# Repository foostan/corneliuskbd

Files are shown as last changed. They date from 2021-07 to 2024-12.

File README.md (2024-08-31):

# Cornelius Keyboard

There are several version.
- v1: Cornelius, [geekhack](https://geekhack.org/index.php?topic=109741.msg2982321#msg2982321)
- v2: Cornelius Low-profile, [youtube](https://youtu.be/LSguWsNrmjk?si=NGWuKMaY3wJwlkxV)

This is the public repository for Cornelius keyboard series.
<p xmlns:cc="http://creativecommons.org/ns#" xmlns:dct="http://purl.org/dc/terms/"><span property="dct:title">Cornelius Keyboard</span> by <span property="cc:attributionName">foostan</span> is licensed under <a href="http://creativecommons.org/licenses/by-nc-sa/4.0/?ref=chooser-v1" target="_blank" rel="license noopener noreferrer" style="display:inline-block;">CC BY-NC-SA 4.0</a></p>

## v1 Cornelius
cornelius-photo
cornelius-details

## v2 Cornelius Low-profile
Pastry Keyboard Cornelius Low-profile (https://youtu.be/LSguWsNrmjk?si=_kJ-U84TBwFJ3C_R)

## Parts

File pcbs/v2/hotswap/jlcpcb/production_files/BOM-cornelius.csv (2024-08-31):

Comment | Designator | Footprint | LCSC
W25Q128JVSIQ | U3 | SOIC-8_5.23x5.23mm_P1.27mm | C113767
1k | R3,R5 | R_0402_1005Metric | C11702
NCP1117-3.3_SOT223 | U2 | SOT-223-3_TabPin2 | C146799
100n | C1,C2,C3,C4,C5,C6,C7,C8,C9 | C_0402_1005Metric | C1525
10u | C15,C16 | C_0402_1005Metric | C15525
27p | C12,C13 | C_0402_1005Metric | C1557
RP2040 | U1 | QFN-56-1EP_7x7mm_P0.4mm_EP3.2x3.2mm | C2040
SOD-523 | D1,D10,D11,D12,D13,D14,D15,D16,D17,D18,D19,D2,D20,D21,D22,D23,D24,D25,D26,D27,D28,D29,D3,D30,D31,D32,D33,D34,D35,D36,D37,D38,D39,D4,D40,D41,D42,D43,D44,D45,D46,D47,D48,D5,D6,D7,D8,D9 | D_SOD-523 | C232841
10k | R4 | R_0402_1005Metric | C25744
27 | R1,R2 | R_0402_1005Metric | C2909343
TS-1088R-02026 | BOOT_SW1,RESET_SW1 | TS-1088R-02026 | C455280
1u | C10,C11,C14 | C_0402_1005Metric | C52923
SW_Push | MX1,MX10,MX11,MX12,MX13,MX14,MX15,MX16,MX17,MX18,MX19,MX2,MX20,MX21,MX22,MX23,MX24,MX25,MX26,MX27,MX28,MX29,MX3,MX30,MX31,MX32,MX33,MX34,MX35,MX36,MX37,MX38,MX39,MX4,MX40,MX41,MX42,MX43,MX44,MX45,MX46,MX47,MX48,MX5,MX6,MX7,MX8,MX9 | keyswitch_choc12_hotswap_1u | C5333465
78171-0004 | J2 | Pico-EZmate_PCB_Header | C588524
12MHz 18pF | Y1 | Crystal_SMD_3225-4Pin_3.2x2.5mm | C91749

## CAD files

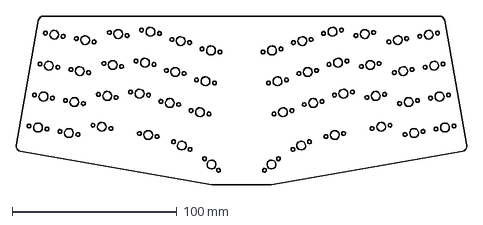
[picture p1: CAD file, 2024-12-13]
foams/v2/switch-ixpe-foam.dxf
273.2 x 102.5 mm

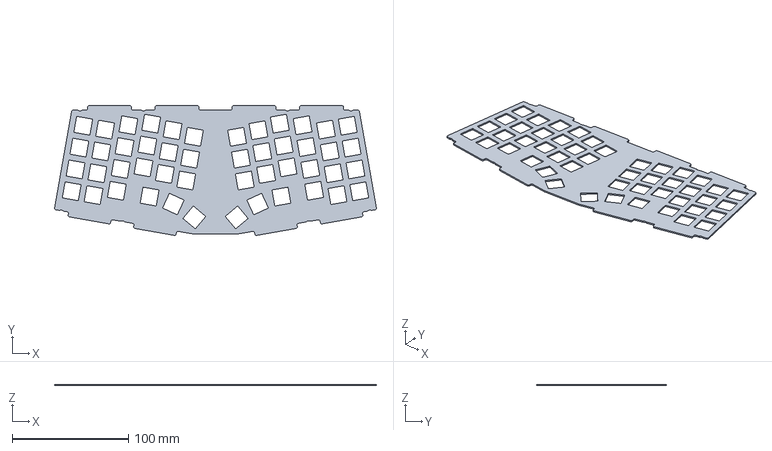
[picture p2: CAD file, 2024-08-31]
plates/v2/switch-plate.step
276.5 x 111.5 x 1.20 mm

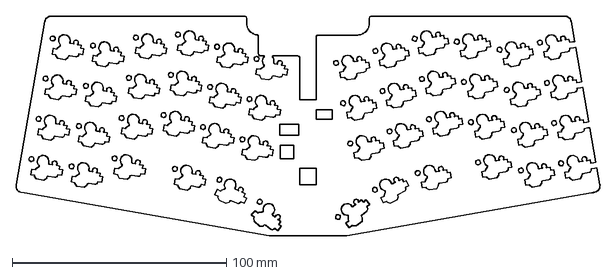
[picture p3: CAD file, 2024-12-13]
foams/v2/middle-foam.dxf
272.3 x 102.5 mm

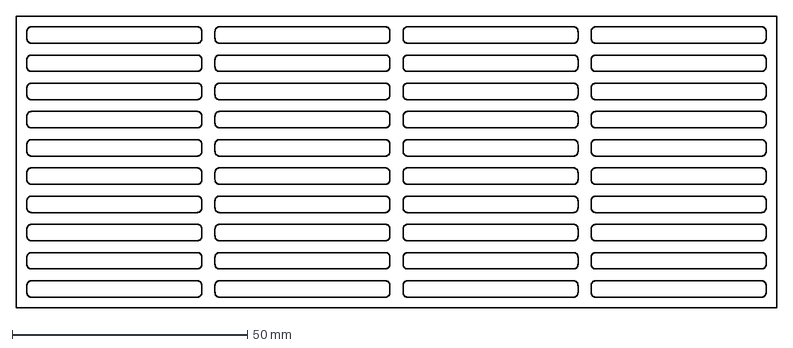
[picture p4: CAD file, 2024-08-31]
foams/v2/gasket-foam.dxf
161.7 x 62.0 mm

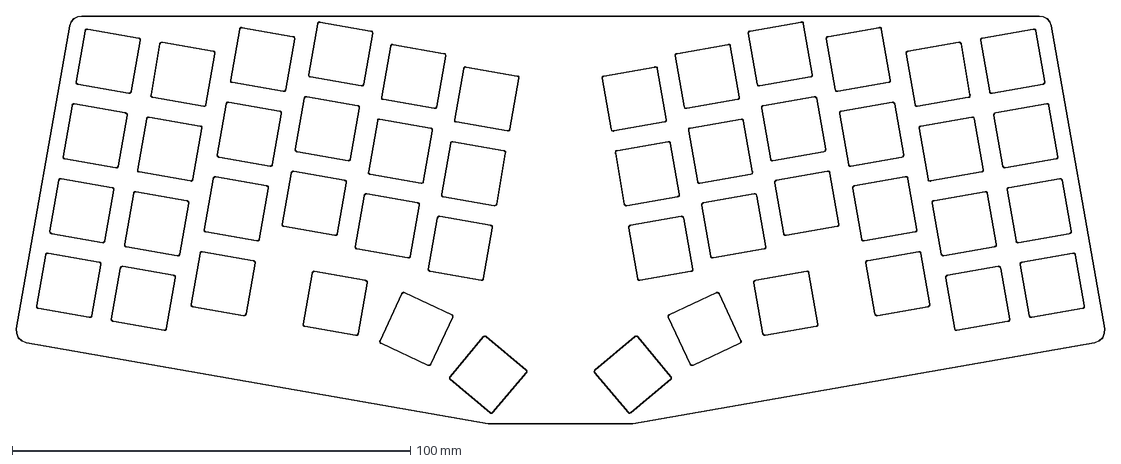
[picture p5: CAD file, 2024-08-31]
foams/v2/switch-foam.dxf
273.2 x 102.5 mm

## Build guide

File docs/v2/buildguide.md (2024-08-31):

# Build Guide / ビルドガイド

Pastry Keyboard Cornelius Low-profile (https://youtu.be/LSguWsNrmjk?si=_kJ-U84TBwFJ3C_R)

## In the box / 箱の中身












## Insert switches / スイッチの取り付け


Please confirm the direction of switches.\
スイッチの向きに注意してください。


Insert the switch foam from the backside of the switches. There are no two sides.\
スイッチの裏側にスイッチフォームをセットします。裏表はありません。



Please insert switches firmly into each socket.\
スイッチをソケットにしっかりと差し込んでください。

## Flash the firmware / ファームウェアの書き込み





Please download uf2 file at here.\
こちらからuf2ファイルをダウンロードしてください。

[cornelius_rev2_via.uf2](https://github.com/foostan/kbd_firmware/raw/main/keyboards/cornelius/qmk/qmk_firmware/.build/cornelius_rev2_via.uf2)

Connect your PC and drop the downloaded uf2 file into the RPI-PR2 device to complete flash.\
PCに接続し、ダウンロードしたuf2ファイルをRPI-PR2デバイスにドロップすると書き込みが完了します。

### When writing firmware for the second time / 2回目以降にファームウェアを書き込む場合


Connect to the PC while holding down the BOOT button, or while connected to the PC, hold down the BOOT button and press the RESET button. After that, an RPI-PR2 device will be mounted.\
BOOTボタンを押しながらPCに接続するか、PCに接続した状態でBOOTボタンを押しながらリセットボタンを押します。 すると、RPI-PR2デバイスがマウントされます。

### Change your keymap / キーマップの書き換え

Please download json file for VIA at here.\
こちらからVIA用のjsonファイルをダウンロードしてください。

[cornelius_rev2.json](https://github.com/foostan/kbd_firmware/raw/main/keyboards/cornelius/the-via/cornelius_rev2.json)

Please reference this [page](https://github.com/foostan/crkbd/blob/main/docs/firmware/rev4/firmware_en.md#change-your-keymap) to change your keymap.\
こちらの[ページ](https://github.com/foostan/crkbd/blob/main/docs/firmware/rev4/firmware_jp.md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)を参考にしてキーマップを書き換えます。

## Attach gasket parts / ガスケットパーツの取り付け




There are 16 attaching points on both sides of the plate in total.\
取り付け場所はプレートの表裏に全部で16箇所あります。

## Mount daughter board / ドーターボードの取り付け



This is the most difficult part of the building.
Please make sure to attach the cable firmly so that it does not come off.\
ここが組み立ての最難関場所です。
ケーブルが外れないようにしっかりと付けてください。





Close the top of the case making sure the foam is correct in place.\
フォームがずれていないことを確認してケースを閉じます。

## Attach rubber feet / ゴム足の取り付け



There are 4 attaching points in total.\
取り付け場所は全部で4箇所あります。

## Attach keycaps / キーキャップの取り付け


## Completed / 完成


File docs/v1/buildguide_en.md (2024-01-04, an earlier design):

# Build Guide
## Checking the package contents
When you open the box, first make sure all the contents are included.

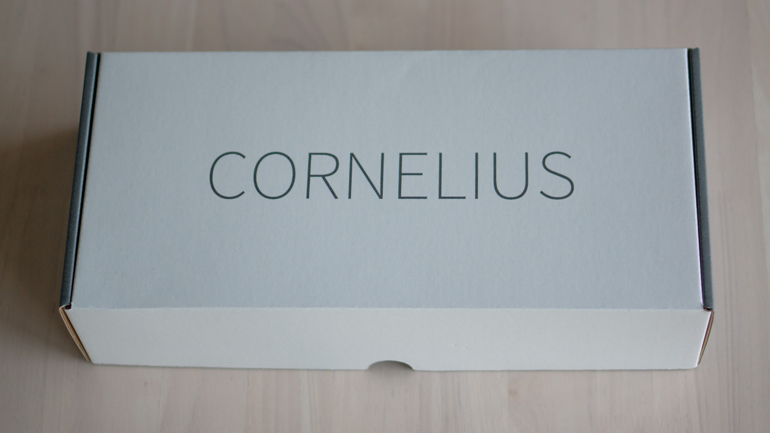
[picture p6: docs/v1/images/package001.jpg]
Package 001


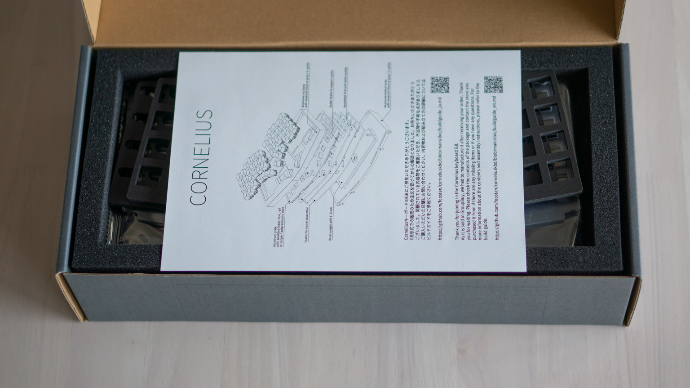
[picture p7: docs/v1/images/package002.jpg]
Package 002


__Keyboard case body__.

The top and bottom bodies are screwed together with spare screws beforehand.
Please remove the screws and check the inside.

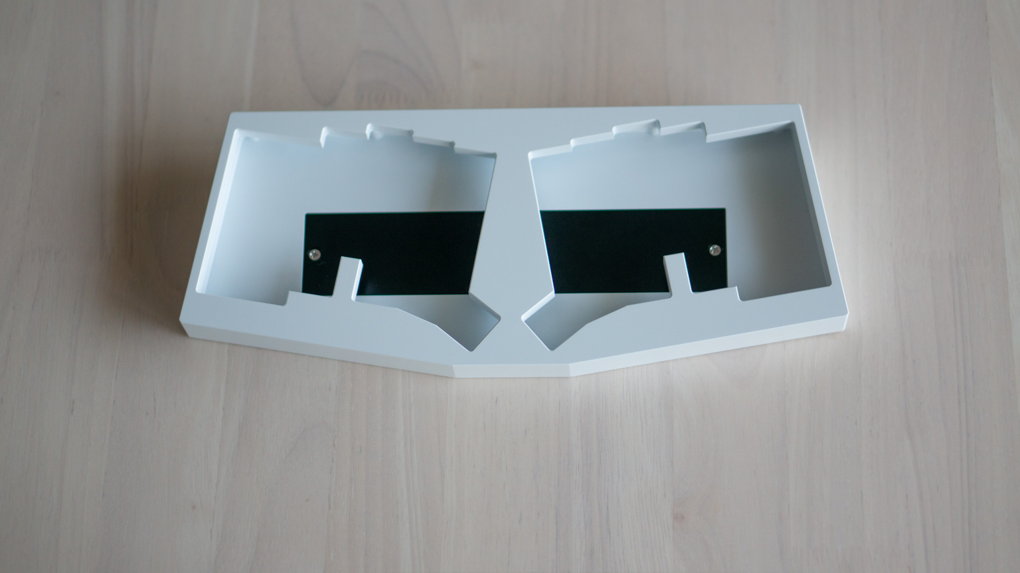
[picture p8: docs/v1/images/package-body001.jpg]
Package Body 001


The inside of the case and other parts that are not visible from the front when assembled may have some scratches or may not be painted sufficiently.
In most cases, this is difficult to prevent due to the manufacturing process, so we appreciate your understanding.

Also, there may be a separate clearance problem with the E-White case, so please refer to [the following](#the-clearance-between-the-e-white-case-and-each-part).

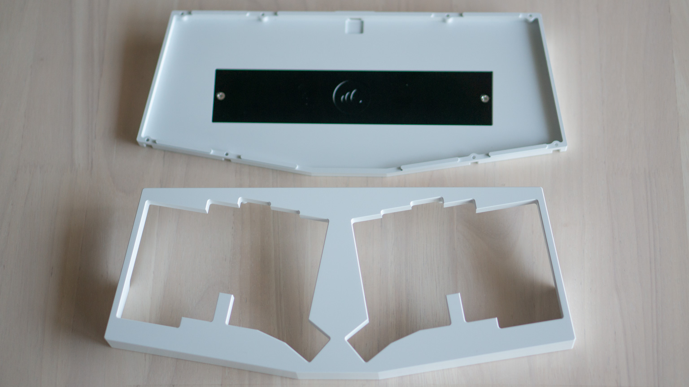
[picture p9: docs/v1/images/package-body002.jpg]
Package Body 002


__PCB__

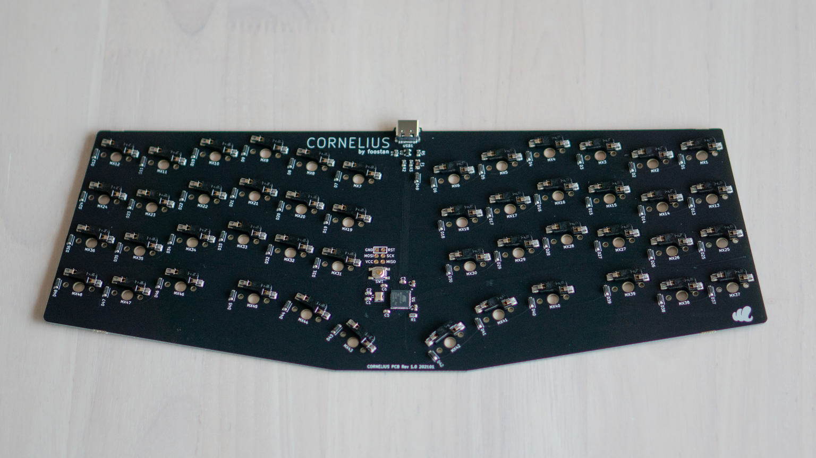
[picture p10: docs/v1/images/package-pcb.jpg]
Package PCB


__Switch plate__

Please make sure the one you have chosen is included.

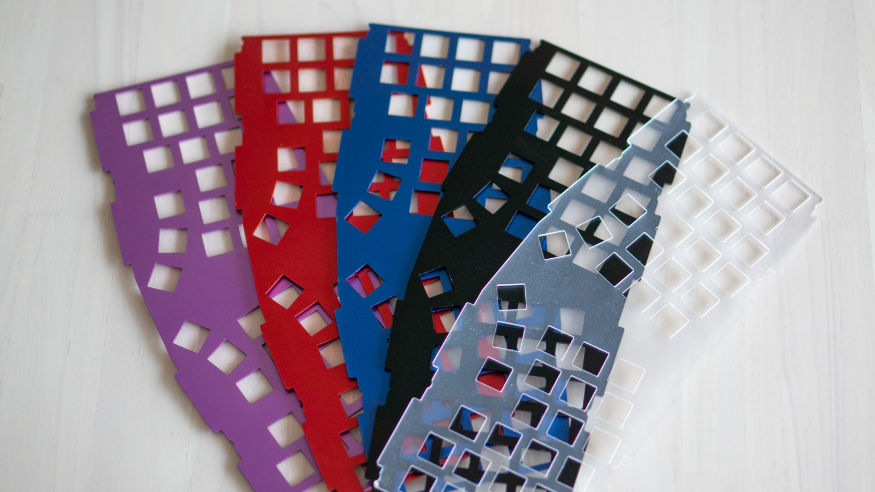
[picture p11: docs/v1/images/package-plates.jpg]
Package Plates


__Foam__

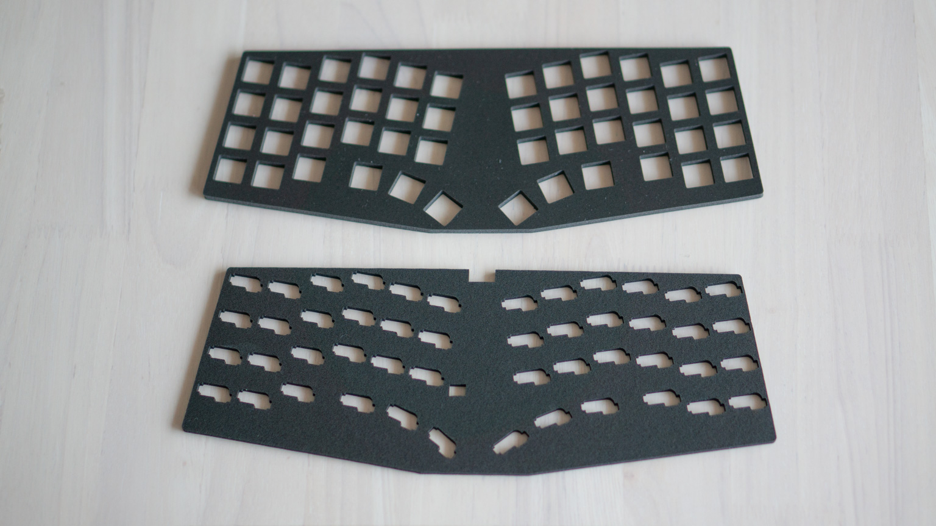
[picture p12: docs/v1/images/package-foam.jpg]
Package Foam


__Gasket foam__

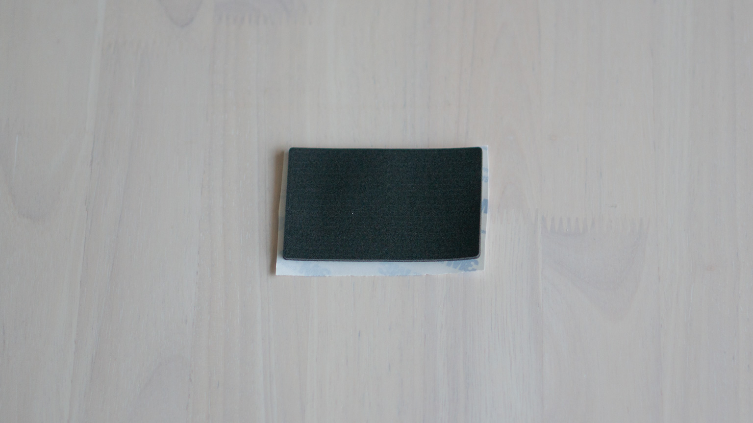
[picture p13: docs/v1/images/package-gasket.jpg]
Package Gasket


__Screws etc.__

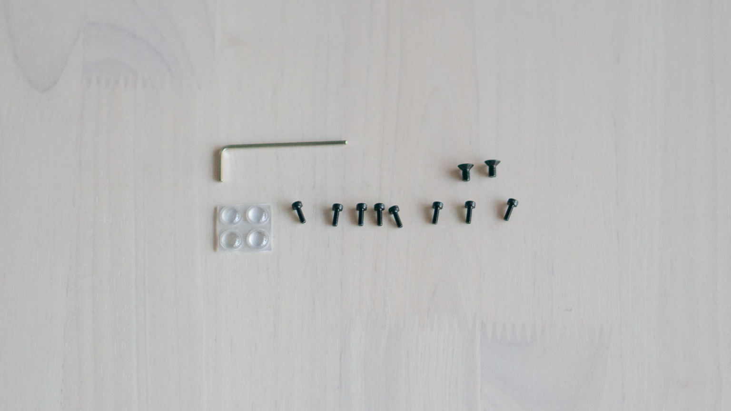
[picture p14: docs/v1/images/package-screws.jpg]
Package Screws


## The clearance between the E-White case and each part

For E-White, some changes were made to the coating process at the GB manufacturing stage to improve quality.
As a result, the surface texture and the white color have been greatly improved.

However, this has resulted in a thicker coating surface than before, which has caused a lack of clearance for some parts.
Specifically, interference may occur between the top body and bottom body, and between the top body and switch plate, depending on the combination of the machining accuracy of each part.

If you are concerned about interference, or if an assembly is difficult, please refer to [the following solutions](#how-to-fix-the-clearance-between-the-e-white-case-and-each-part).
Please check and deal with them before assembly.
Additionally, some of them have been handled for us before shipment.

## Check PCB operation

Before you start assembling, please make sure that the PCB is working properly.

We recommend you to use [VIA](https://caniusevia.com/) or [Remap](https://remap-keys.app/) to check the operation, since VIA-compatible firmware has already been written.

BTW, when you need to use the newest firmware then you should confirm [here](https://github.com/foostan/crkbd/blob/main/doc/firmware_en.md) as a reference to flash.
Download the firmware of VIA from the following link.

[foostan_cornelius_via.hex](https://raw.githubusercontent.com/foostan/qmk_firmware-hex/main/.build/foostan_cornelius_via.hex)

__Verification with VIA's Test Matrix__

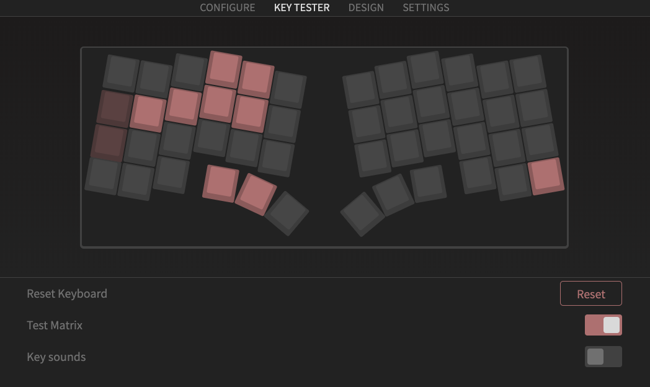
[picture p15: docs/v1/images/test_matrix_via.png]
Test Matrix by VIA


__Verify by Test Matrix by Remap__

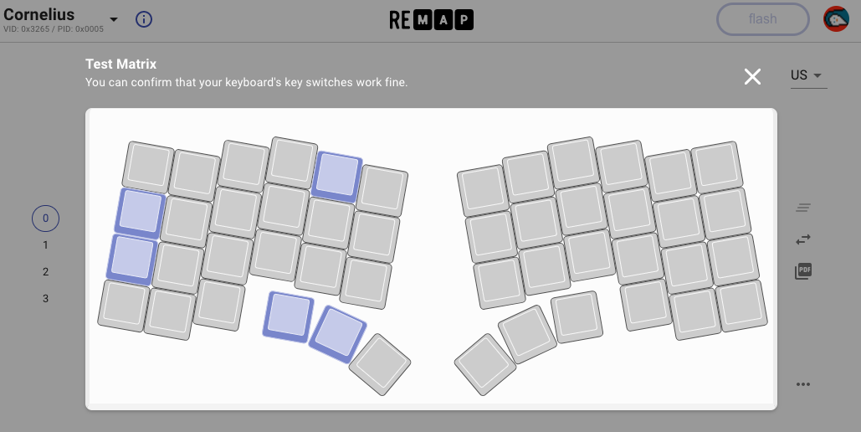
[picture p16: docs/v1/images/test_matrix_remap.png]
Test Matrix by Remap


## Install the gasket foam.

Install the gasket foam on the bottom body and the top body.
You can also install it on the switch plate instead of the case.

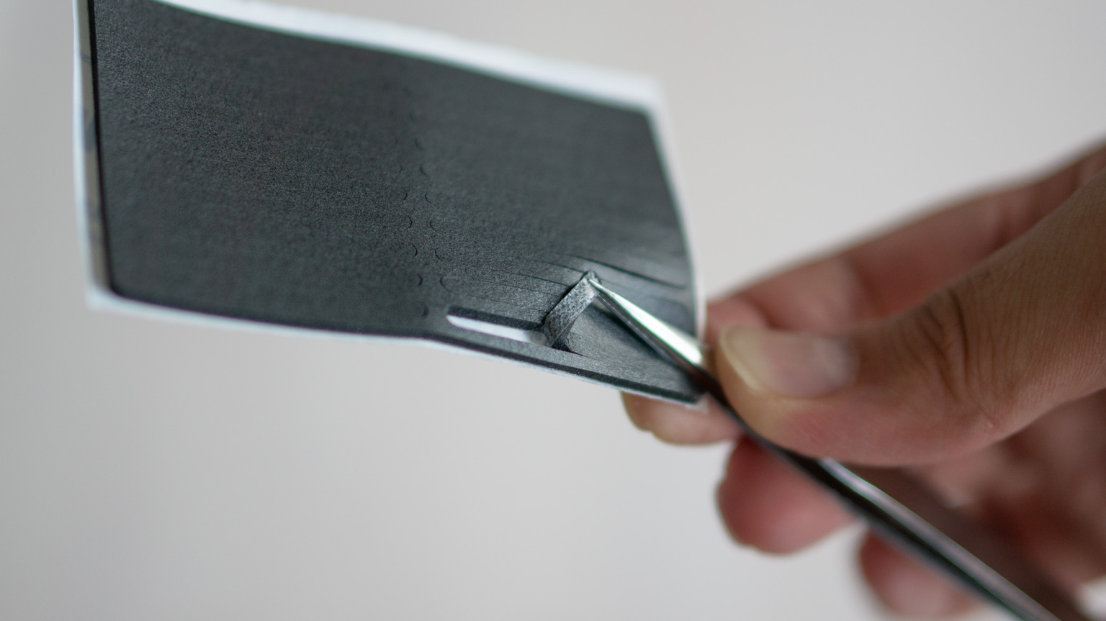
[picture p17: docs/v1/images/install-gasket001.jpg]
Install Gasket


When removing the gasket foam, be careful not to tear the foam.
Also, there is adhesive tape on one side of the gasket foam. Depending on how you remove it, the adhesive side may remain on the filme side, so it is recommended to carefully remove it with tweezers.

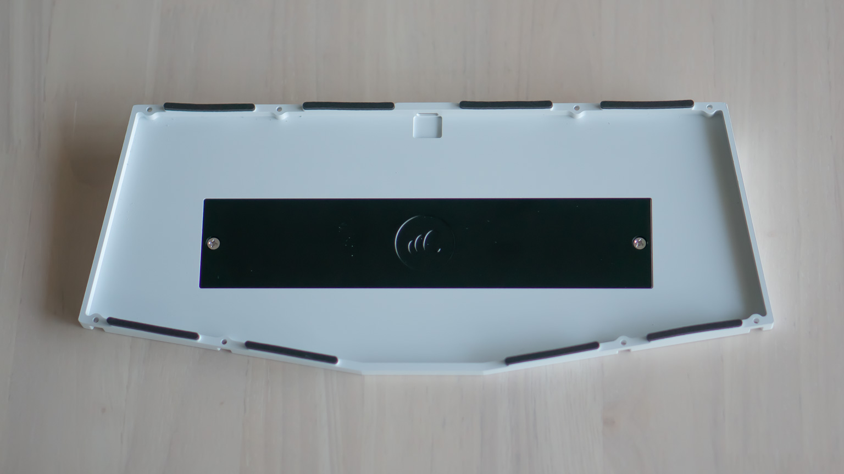
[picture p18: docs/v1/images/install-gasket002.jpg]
Install Gasket


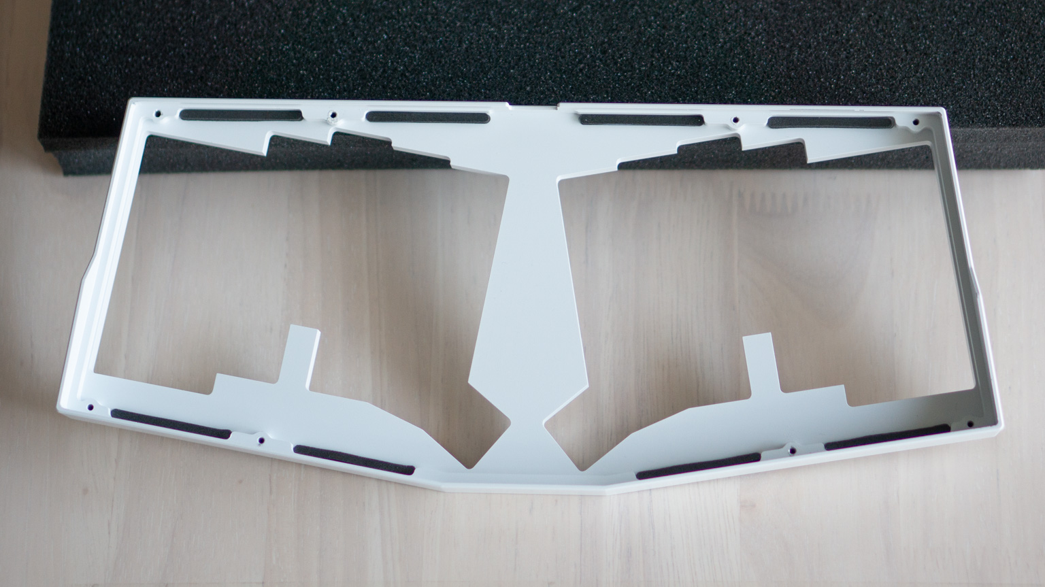
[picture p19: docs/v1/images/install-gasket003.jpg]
Install Gasket


## Installing the switch

For the polycarbonate plate, there is a protective film on both sides, so carefully peel it off.

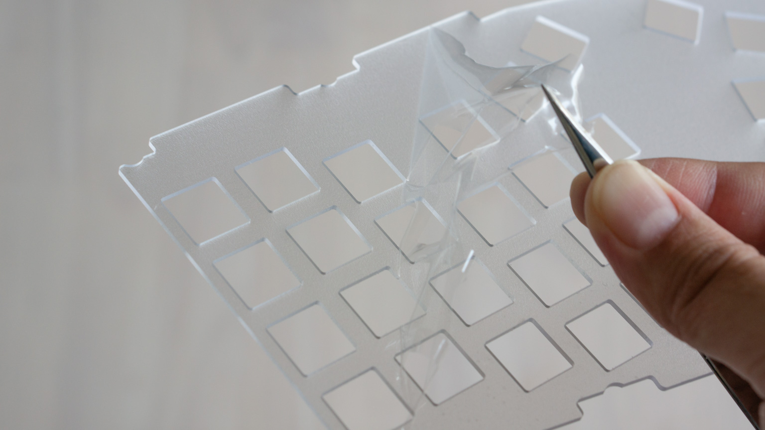
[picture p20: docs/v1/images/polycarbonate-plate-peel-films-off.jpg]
Polycarbonate plate Peel films off


The polycarbonate plate has a glossy side and a semi-glossy side. The two sides of the plate are the same, so you can use whichever side you prefer.

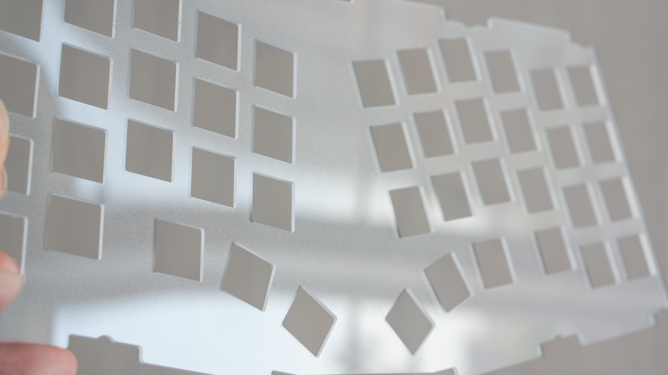
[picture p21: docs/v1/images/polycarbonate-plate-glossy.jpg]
Polycarbonate plate Glossy


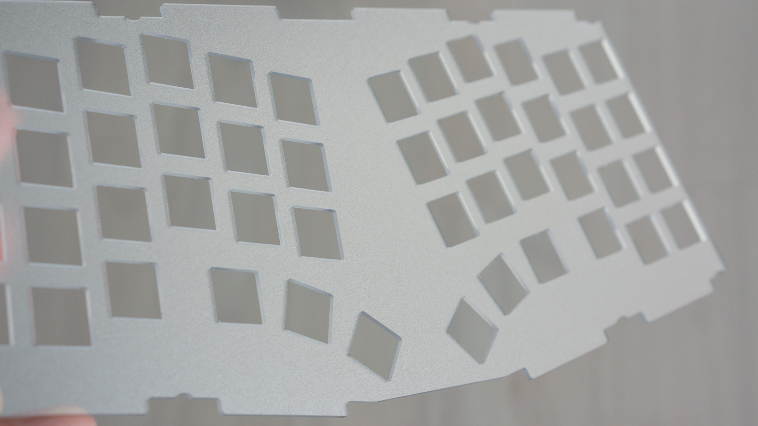
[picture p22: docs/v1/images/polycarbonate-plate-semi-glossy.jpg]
Polycarbonate plate Semi-Glossy


Insert the switch foam between the PCB and the switch plate, and then attach the switch.

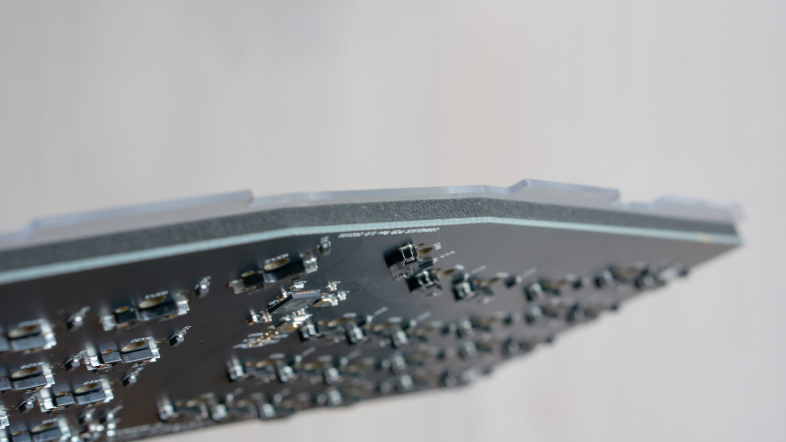
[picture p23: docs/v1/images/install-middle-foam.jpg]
Install Middle foam


When attaching the switch, press it straight down from the top.
Place the PCB on a flat surface as shown in the photo, and push it in from directly above for easier insertion.

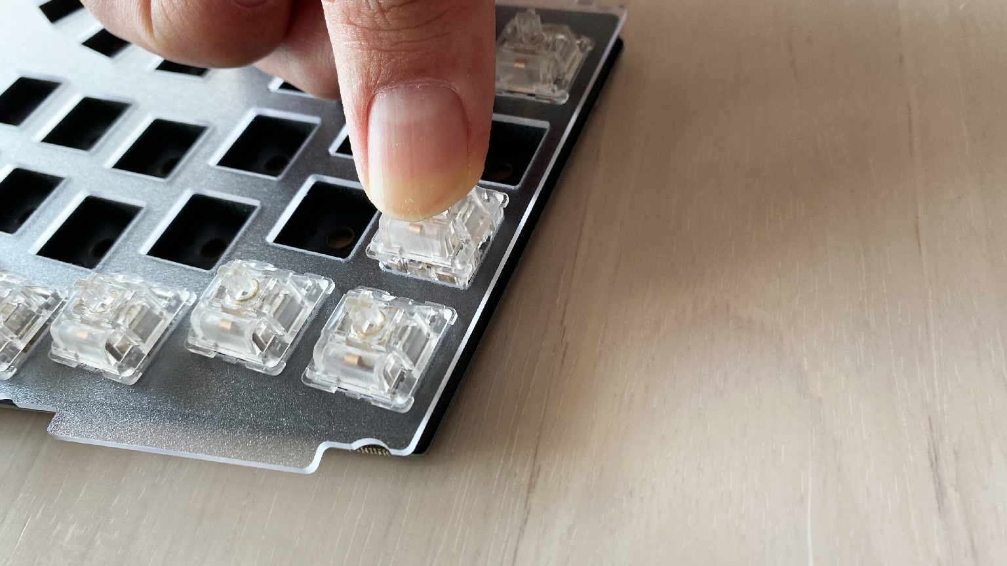
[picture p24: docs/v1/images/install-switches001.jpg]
Install Switches 001


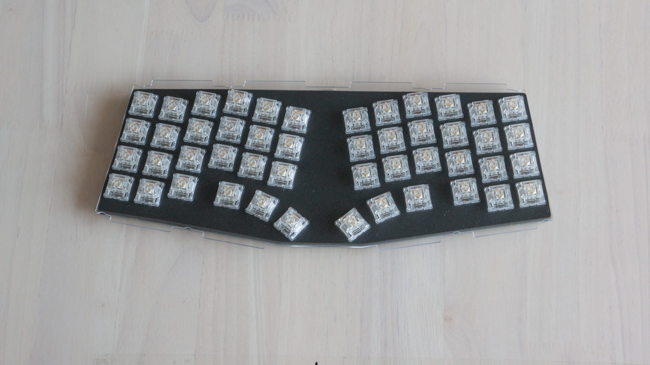
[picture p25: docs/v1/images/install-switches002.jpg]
Install Switches 002


If you are using a solderable board, you can also solder it here.

## Case assembly

The weights on the bottom body are initially attached with silver screws.
You can change them to black screws if you like.

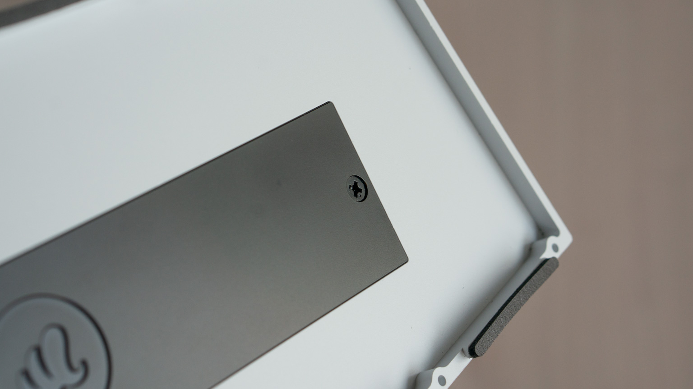
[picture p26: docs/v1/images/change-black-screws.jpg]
Change black screws


Put the bottom foam on the bottom of the bottom body, and put the PCB on top of it.

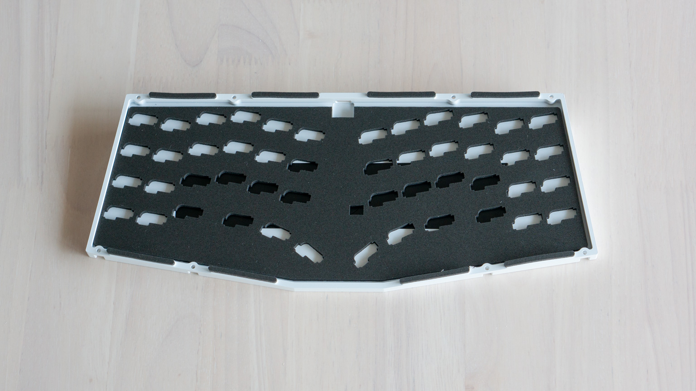
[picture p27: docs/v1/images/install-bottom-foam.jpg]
Install a bottom foam


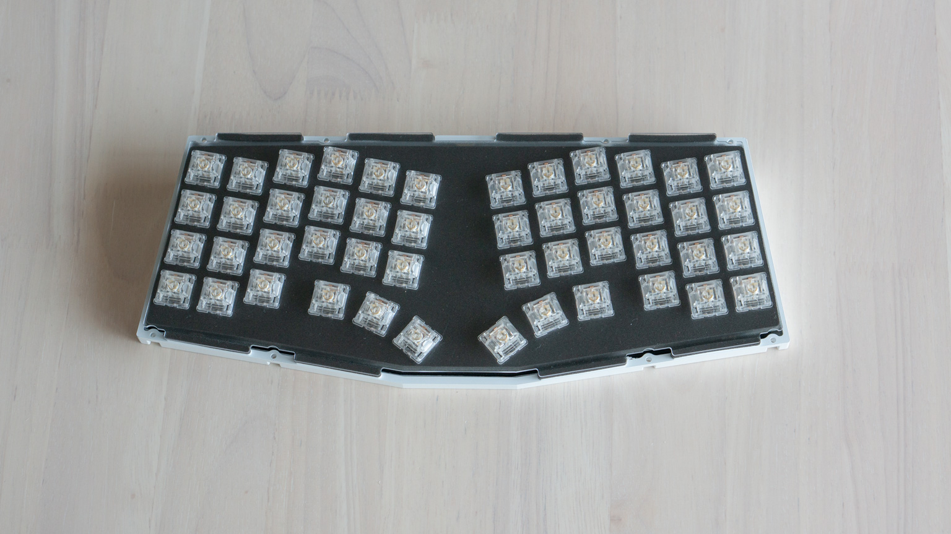
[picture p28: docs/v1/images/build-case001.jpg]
Build a case 001


Install the top body straight from the top and while holding the top body by hand to prevent it from coming off, attach the screws from the back.

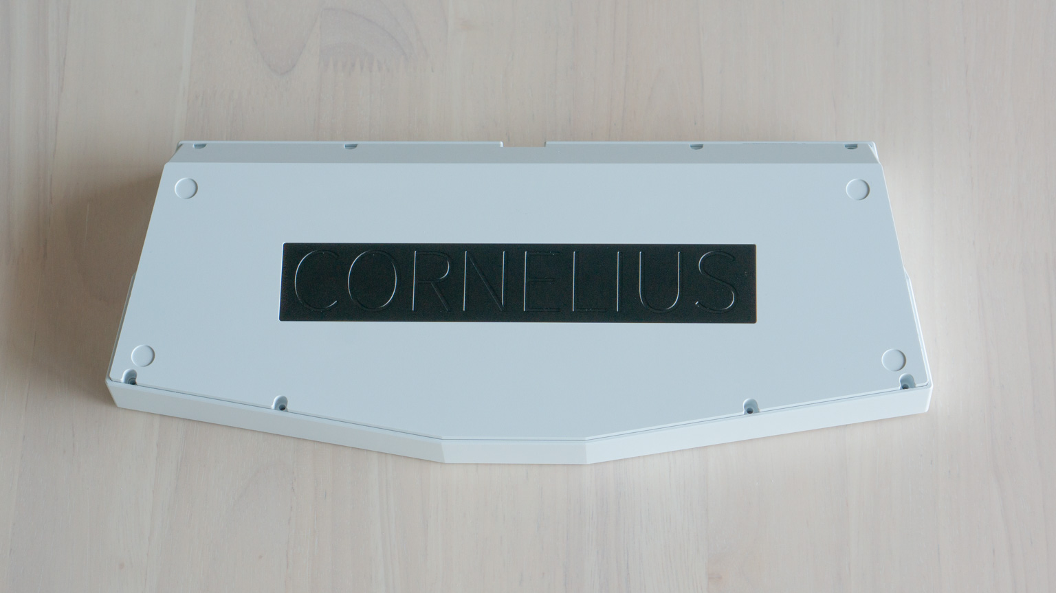
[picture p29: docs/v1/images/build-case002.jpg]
Build a case 002


Attach cushion rubbers.

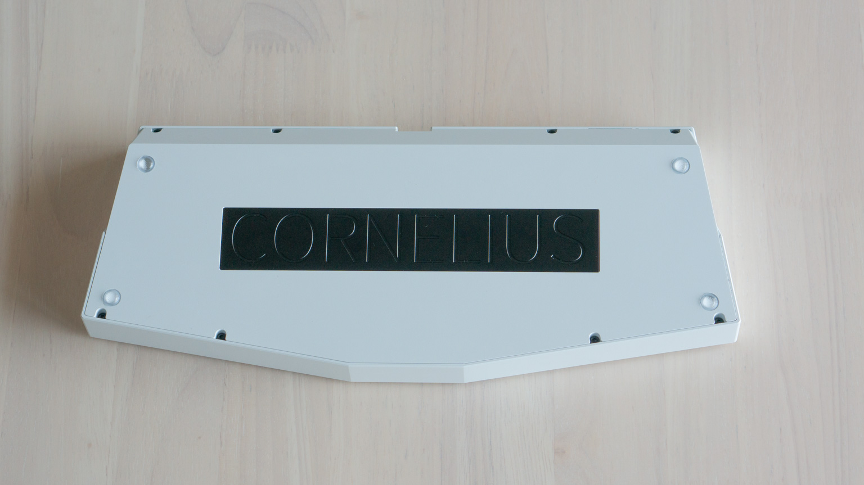
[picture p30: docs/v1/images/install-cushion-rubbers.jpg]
Install cushion rubbers


Finally, attach the key cap to complete the process.

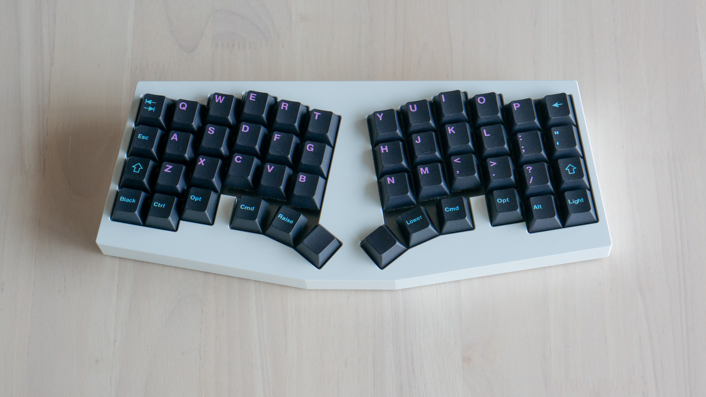
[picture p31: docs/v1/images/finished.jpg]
Finished


## how to fix the clearance between the E-White case and each part

The following is a step-by-step explanation of how to fix with interference between the top body and bottom body, and between the top body and plate.
Please note that it is necessary to remove about 0.1mm-0.2mm with a sandpaper. In the example shown here, we used a JIS standard #240. If you use a sandpaper with too rough a grit, it may damage the main body greatly, so it is safer to use a medium to fine grit sandpaper of #240-#400.

The number of the sandpaper varies depending on the standard. The JIS standard #240-#400 is roughly the same as the following for other standards.
- The United States CAMI: 240-320
- The European FEPA: P220-P400

The degree of shaving varies depending on the individual unit, so please check each time while working to avoid over-shaving.
I apologize for any inconvenience this may cause.

### When the top body and bottom body interfere with each other

If you feel a little resistance when opening and closing the top and bottom bodies, there is no problem.
However, if you feel it is too tight, first lightly scrape the following area on the bottom body.
It depends on the individual, but please refer to the following pictures.

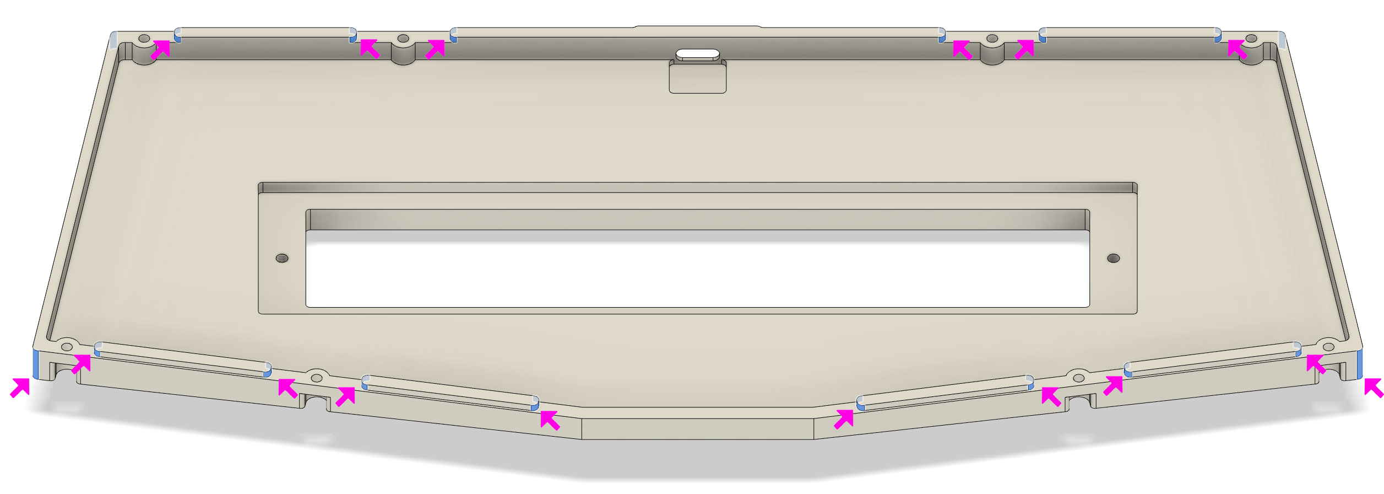
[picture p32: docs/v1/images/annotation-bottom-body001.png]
Annotation Bottom body 001


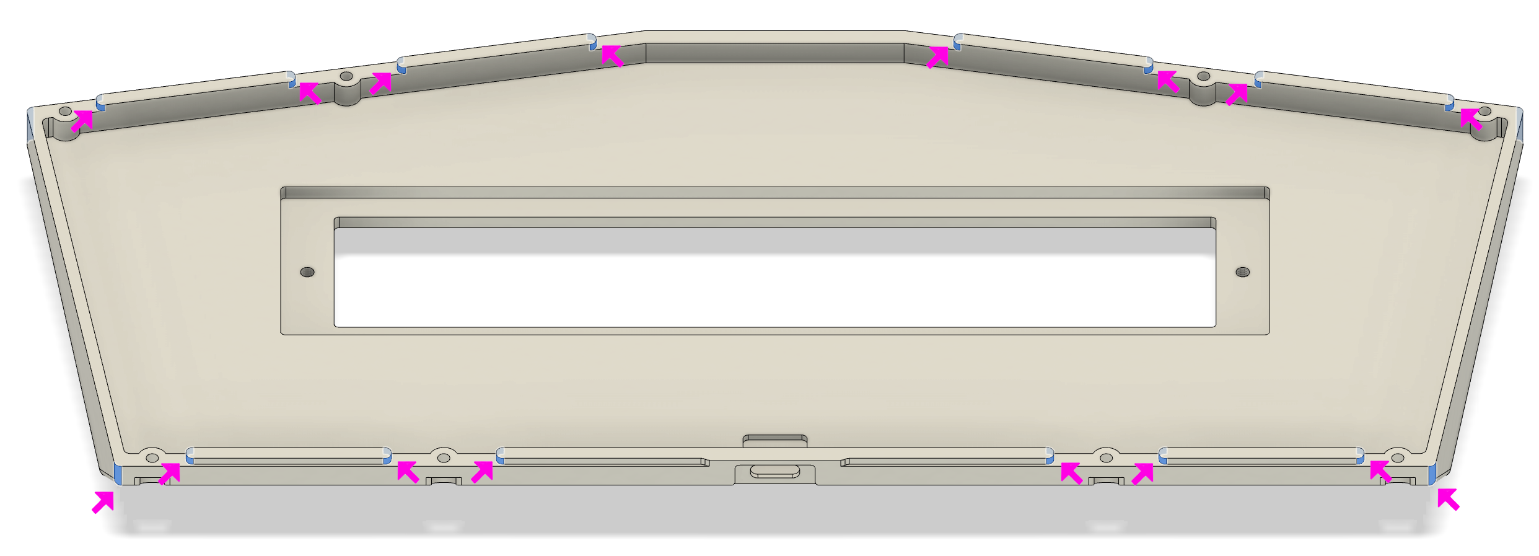
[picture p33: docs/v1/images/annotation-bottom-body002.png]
Annotation Bottom body 002


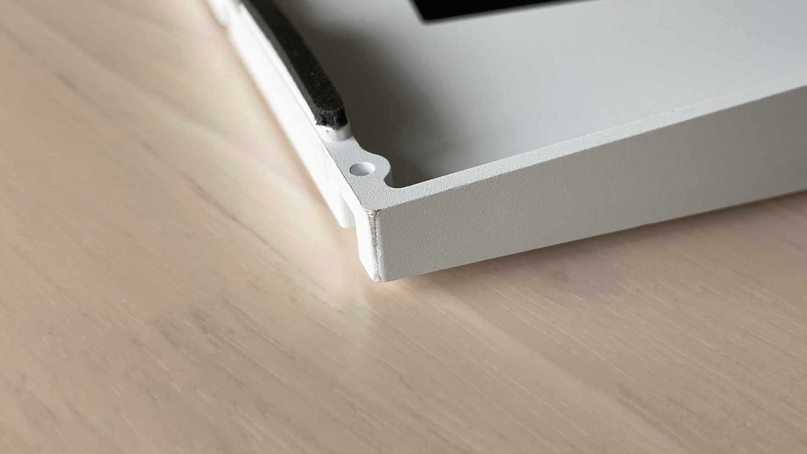
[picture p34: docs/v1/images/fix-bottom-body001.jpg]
Fix Bottom body 001


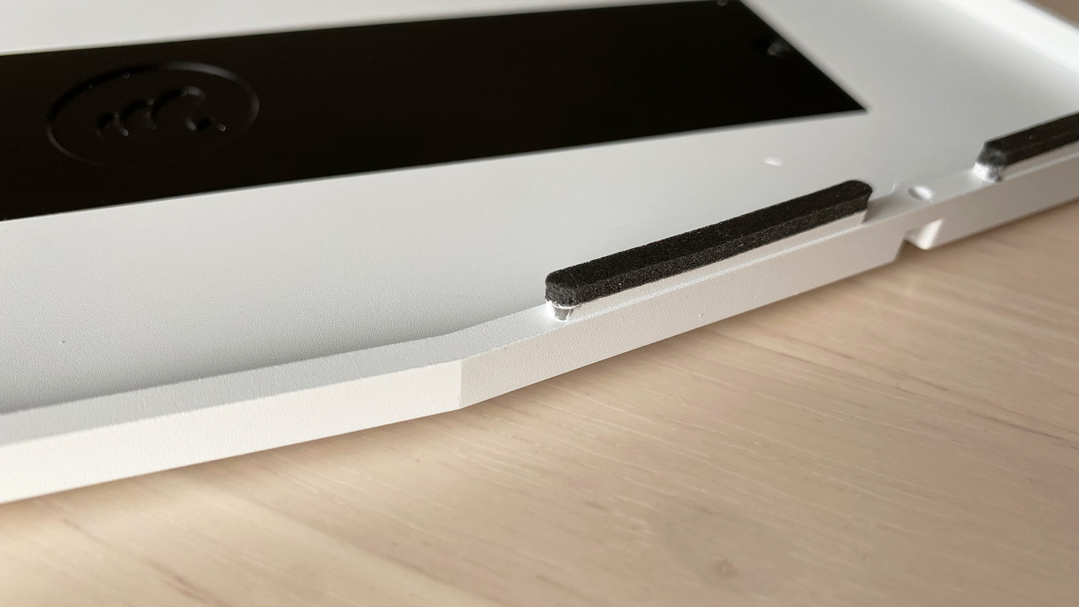
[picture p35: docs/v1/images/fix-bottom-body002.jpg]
Fix Bottom body 002


If the bottom body does not solve the problem, lightly scrape the following areas on the top body.
However, it is not recommended to shave this area as it is difficult to do so.

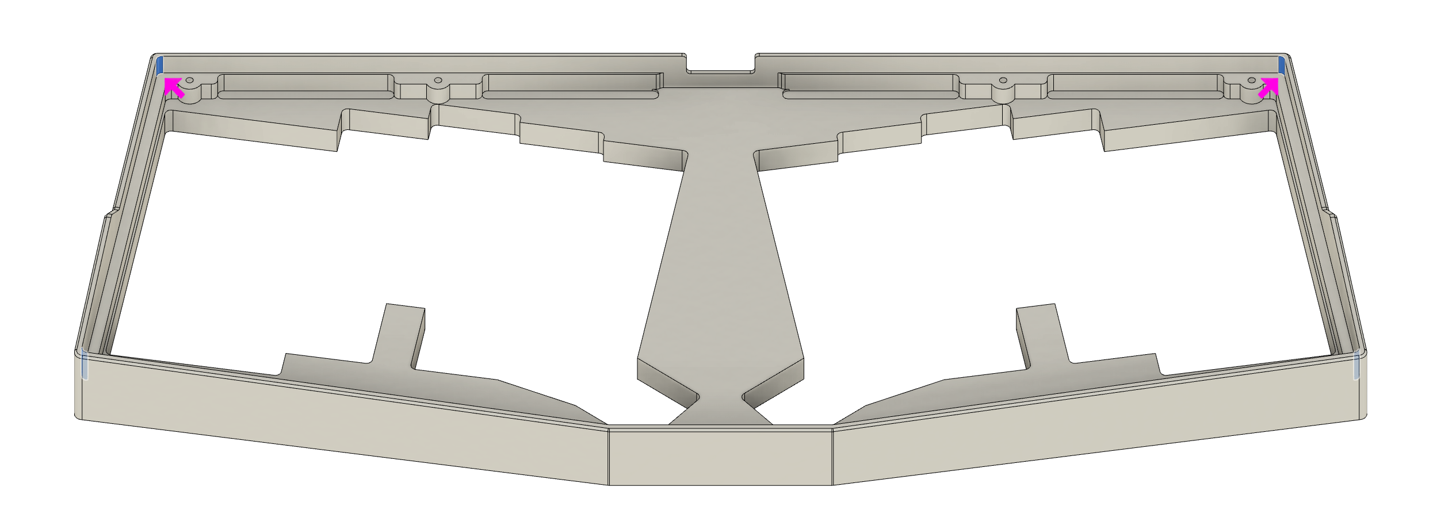
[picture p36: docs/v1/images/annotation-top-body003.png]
Annotation Top body 003


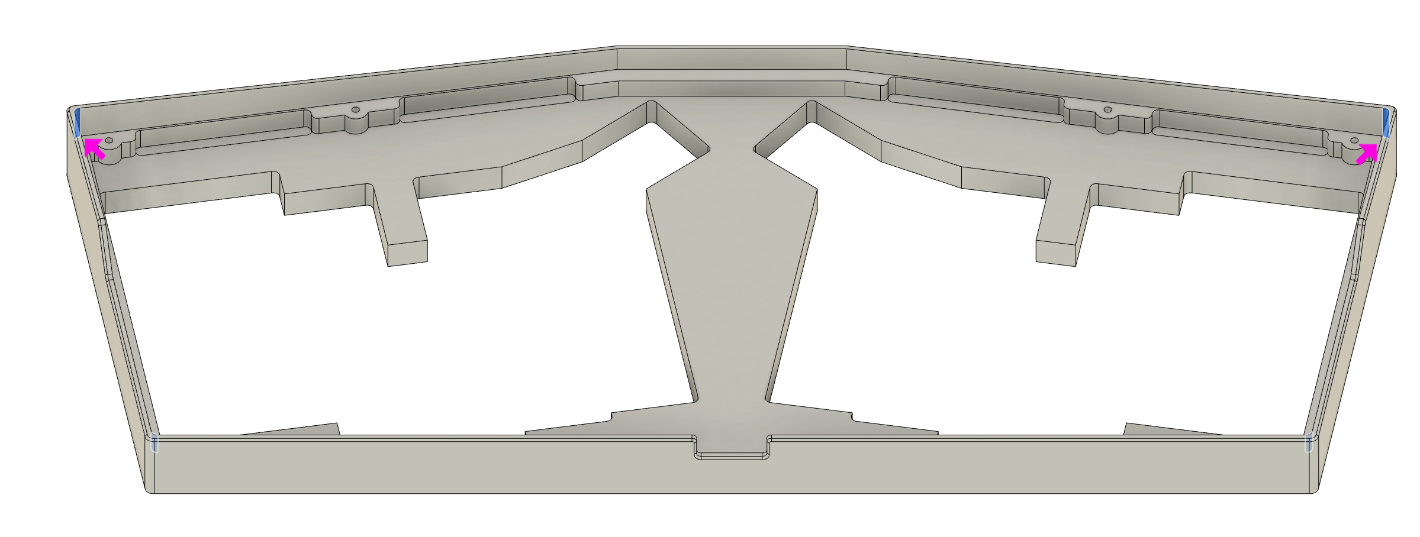
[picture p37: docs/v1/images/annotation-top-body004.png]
Annotation Top body 004


### When the top body and plate interfere with each other

First, please check how much interference there is.
Due to the nature of the gasket mount, if it interferes to the extent that you feel resistance, it will affect the feel.

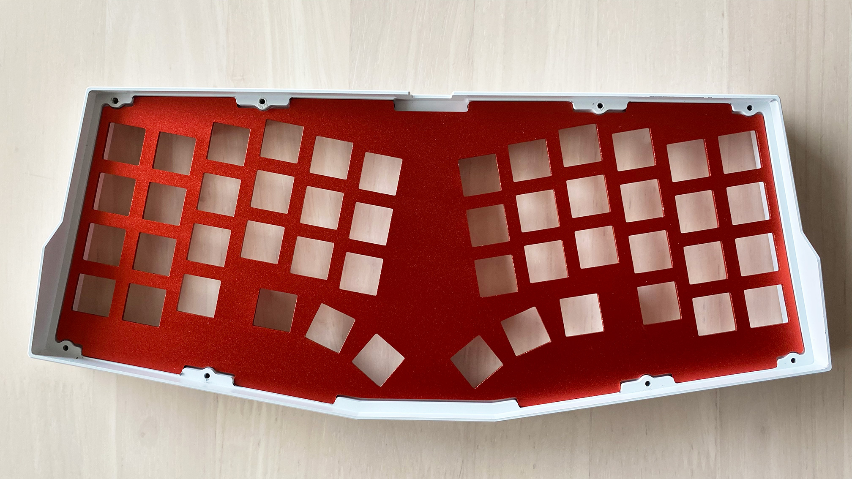
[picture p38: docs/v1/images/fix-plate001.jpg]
Fix Plate 001


If you feel resistance, first lightly scrape the following places on the plate.
It depends on the individual, but please refer to the following pictures.

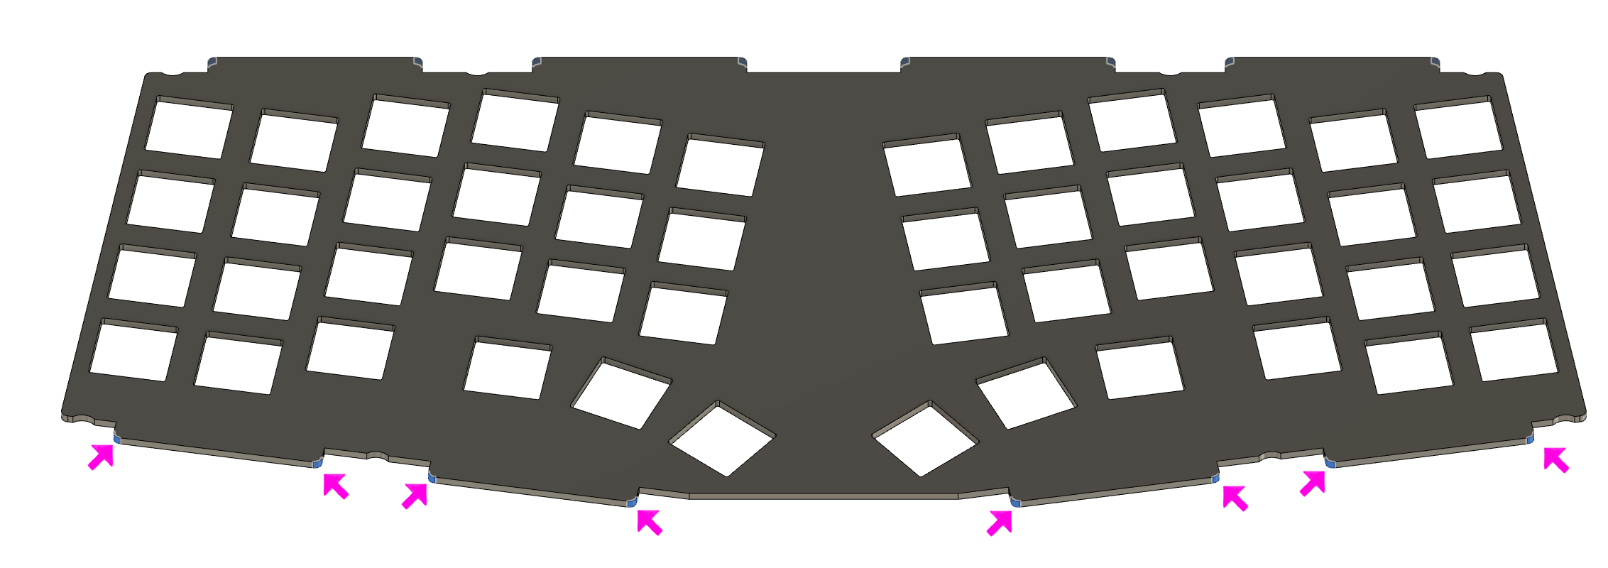
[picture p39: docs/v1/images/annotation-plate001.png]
Annotation Plate 001


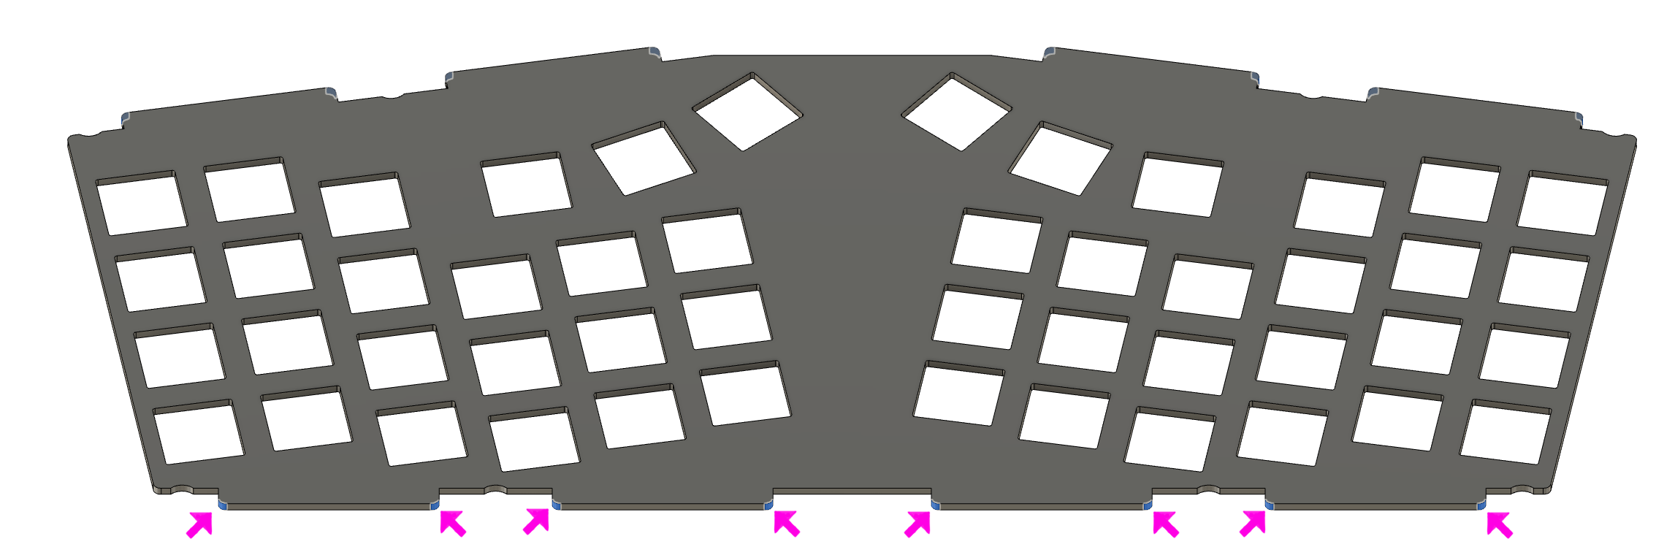
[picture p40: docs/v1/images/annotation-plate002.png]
Annotation Plate 002


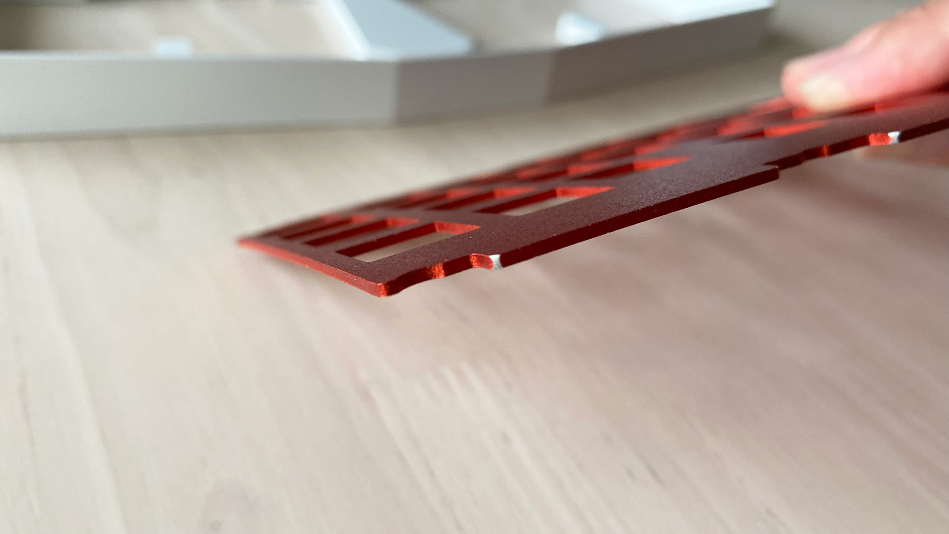
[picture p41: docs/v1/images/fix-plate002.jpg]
Fix Plate 001


If the problem is not solved by the plate side, lightly scrape the following areas on the top body.
However, it is not recommended to shave this area as it is difficult to do so.

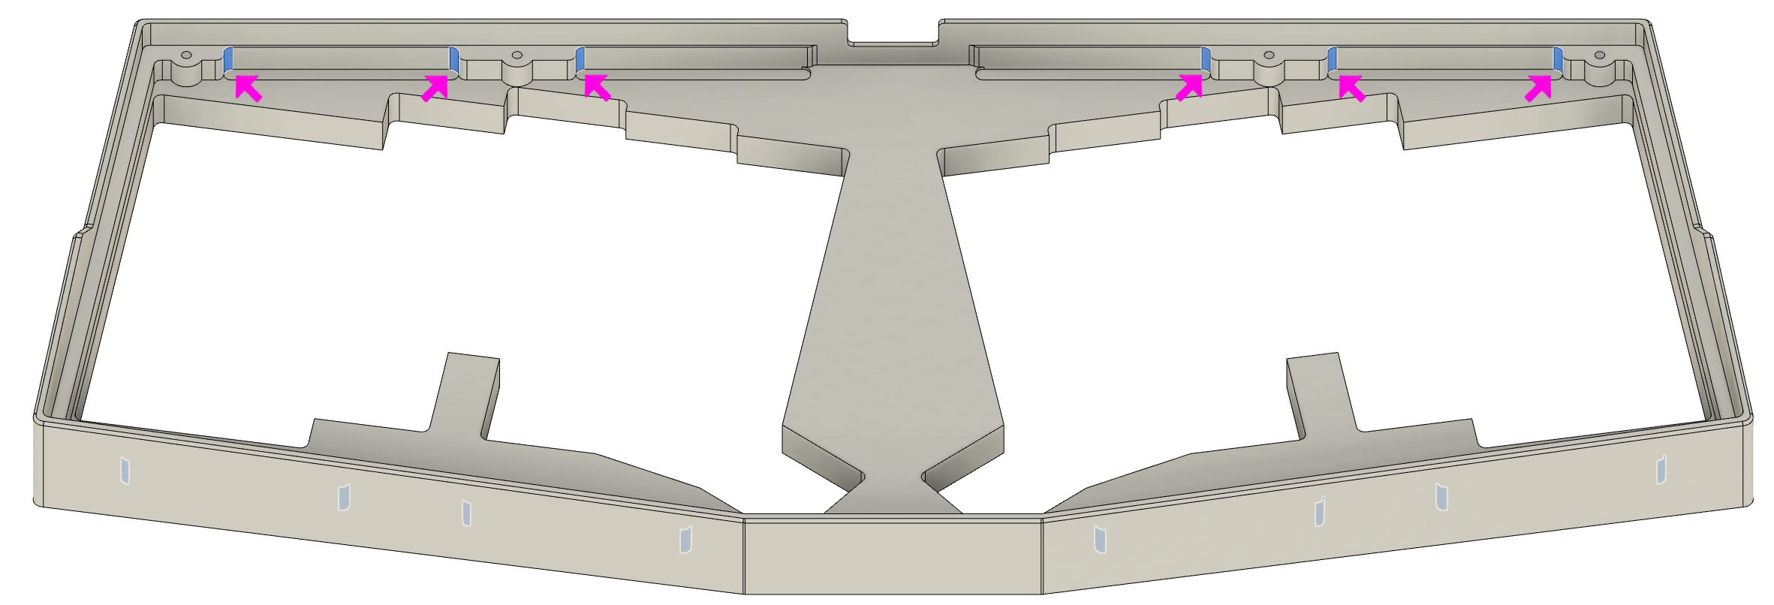
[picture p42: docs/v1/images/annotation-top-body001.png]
Annotation Top body 001


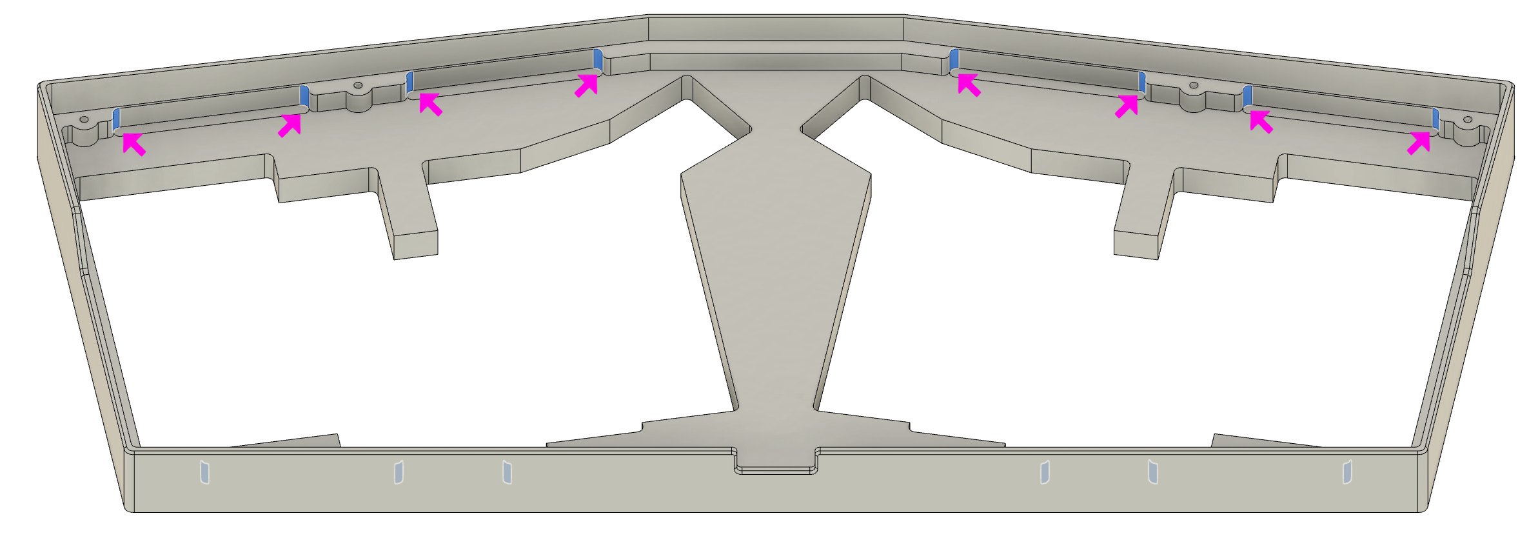
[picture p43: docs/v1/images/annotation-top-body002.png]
Annotation Top body 001


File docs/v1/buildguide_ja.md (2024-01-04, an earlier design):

# ビルドガイド

## パッケージ内容の確認
箱を開けたらまずは内容物が全て入っているか確認してください。

Package 001

Package 002

__キーボードケース本体__

予め予備のネジで上下のボディがネジ止めされています。
ネジを外して中をご確認してください。

Package Body 001

ケースの内部など、組み立てたときに表から見えない部分については多少の傷や塗装が十分にされていない場合があります。
これは製造工程の都合で防ぐことが難しいものとなっています、ご理解頂けますと幸いです。

またE-Whiteケースにつきましては別途クリアランスの問題が発生している場合がありますので[下記](#E-Whiteケースと各パーツのクリアランスについて)をご参照ください。

Package Body 002

__PCB__

Package PCB

__スイッチプレート__

ご自身の選んだものが入っていることをご確認してください。

Package Plates

__フォーム__

Package Foam

__ガスケットフォーム__

Package Gasket

__ネジ類__

Package Screws

## E-Whiteケースと各パーツのクリアランスについて

E-Whiteについて、GBの製造段階で品質向上のためコーティング工程に一部変更がありました。
これにより表面の質感や白の色味が大幅に改善されました。

しかしこれによって従来よりも塗装面が厚くなり一部パーツのクリアランス不足が発生しております。
具体的には、トップボディとボトムボディ、トップボディとスイッチプレートにおいて、各パーツの削り出し精度の組み合わせによって干渉を起こす場合があります。
ケースの内側であるという点、キーボードの性能上の問題はないという点でこのままの出荷となったことをご理解いただけますと幸いです。

干渉について気になる方、組み立てが困難な場合は[下記対処方法](#E-Whiteケースと各パーツのクリアランスに関する対処方法)をご参照ください。
また組立前にご確認、ご対応して頂ければと思います。
なお出荷の段階でこちらで対処したものも含まれています。

## PCBの動作確認

組み立てを始める前にPCBが正常に動作することをご確認してください。

既にVIA対応のファームウェアが書き込まれた状態なので、動作確認には [VIA](https://caniusevia.com/) もしくは [Remap](https://remap-keys.app/) を利用することをおすすめします。

なお最新のファームウェアを利用する場合は [こちら](https://github.com/foostan/crkbd/blob/main/doc/firmware_jp.md) を参考にしてください。
VIA用のファームウェアはこちらは下記よりダウンロードできます。

[foostan_cornelius_via.hex](https://raw.githubusercontent.com/foostan/qmk_firmware-hex/main/.build/foostan_cornelius_via.hex)

__VIAのTest Matrixによる確認__

Test Matrix by VIA

__RemapのTest Matrixによる確認__

Test Matrix by Remap

## ガスケットフォームの取り付け

ボトムボディおよびトップボディの該当位置にそれぞれガスケットフォームを取り付けます。
なおケースではなくスイッチプレートに取り付けても問題ありません。

Install Gasket

なおガスケットフォームを取り外すときはフォームを破らないようにお気を付けください。
またガスケットフォームの片面には粘着テープが付いています。剥がし方によって粘着面がフィルム側に残ってしまう場合があるのピンセットで丁寧に取ることをおすすめします。

Install Gasket

Install Gasket

## スイッチの取り付け

ポリカーボネートプレートの場合は、両面に保護フィルムが付いているので丁寧に剥がします。

Polycarbonate plate Peel films off

ポリカーボネートプレートは光沢面と半光沢面があります。プレートは裏表同じなのでお好きな方を表にしてお使いください。

Polycarbonate plate Glossy

Polycarbonate plate Semi-Glossy

PCBとスイッチプレートの間にスイッチ用のフォームを挟み込み、スイッチを付けていきます。

Install Middle foam

スイッチを取り付けるときはまっすぐに上から押し付けるようにして付けます。
写真のようにPCBを平らな場所に置き、真上から押し込むと入れやすいです。

Install Switches 001

Install Switches 002

また、はんだ付け版の基板の場合はここではんだ付けも行います。

## ケースの組み立て

ボトムボディに付いているウェイトは、最初は銀色のネジで付けられています。
お好みに応じて黒色のネジに変更ができます。

Change black screws

ボトムボディの底にボトム用のフォームを敷き、その上からPCBを乗せます。

Install a bottom foam

Build a case 001

トップボディを上からまっすぐに取り付け、裏からネジを付けていきます。

Build a case 002

クッションゴムを付けます。

Install cushion rubbers

最後にキーキャップを取り付けて完成です。

Finished

## E-Whiteケースと各パーツのクリアランスに関する対処方法

トップボディとボトムボディが干渉する場合とトップボディとプレートが干渉する場合の対処方法をそれぞれ順を追って説明します。

なお指定箇所を紙ヤスリ等で0.1mm-0.2mm程削って頂く必要があります。掲載する対処の例ではJIS規格の#240の紙ヤスリを使用しました。
あまり目の荒いヤスリを使用すると本体を大きく傷つけてしまう恐れがあるので#240-#400番の中目から細目の紙ヤスリを使用すると安心です。

個体によって削る程度が異なりますので削り過ぎないよう都度確認しながら作業して頂ければと思います。
お手数おかけして申し訳ございません、よろしくお願いします。

### トップボディとボトムボディが干渉する場合

トップボディとボトムボディの開け閉めで少し抵抗がある程度であれば問題ありませんが、きつく感じる場合はまずはボトムボディの下記の場所を軽く削ってください。
個体差にもよりますが、下記写真をご参考にしてください。

Annotation Bottom body 001

Annotation Bottom body 002

Fix Bottom body 001

Fix Bottom body 002

ボトムボディ側の対応で解決しない場合、トップボディの下記の場所を軽く削って下さい。
ただしこちらに関しては削るのが難しい箇所となりますので、こちらを削ることはあまりおすすめしません。

Annotation Top body 003

Annotation Top body 004

### トップボディプレートが干渉する場合

まずはどの程度干渉するかご確認してください。
ガスケットマウントという特性上、抵抗を感じる程度干渉している場合は打鍵感に影響します。

Fix Plage 001

抵抗を感じる場合はまずはプレートの下記の場所を軽く削って下さい。
個体差にもよりますが、下記写真をご参考にしてください。

Annotation Plate 001

Annotation Plate 002

Fix Plate 001

プレート側の対応で解決しない場合、トップボディの下記の場所を軽く削って下さい。
ただしこちらに関しては削るのが難しい箇所となりますので、こちらを削ることはあまりおすすめしません。

Annotation Top body 001

Annotation Top body 001

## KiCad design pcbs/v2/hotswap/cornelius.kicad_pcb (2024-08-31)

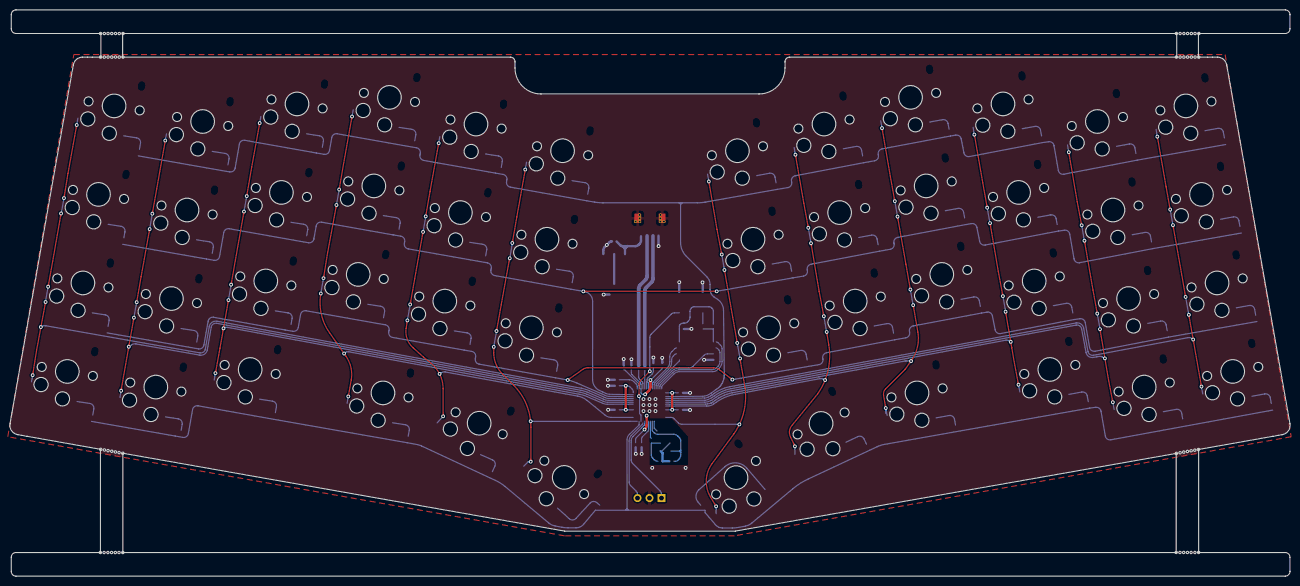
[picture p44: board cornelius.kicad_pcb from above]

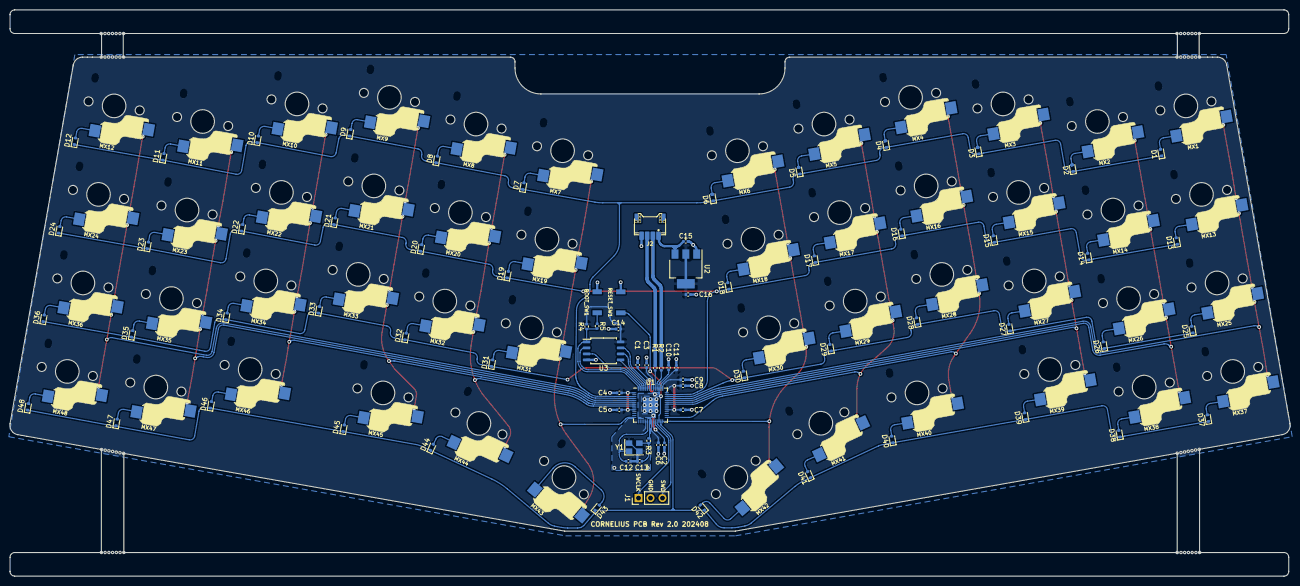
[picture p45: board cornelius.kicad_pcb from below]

Board: 2 copper layers, 271.3 x 120.0 mm, 133 parts (125 on the bottom side), 85 nets.

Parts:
B1, B2, B3, B4, B5, B6, B7, B8: BreakAwayTab; Breakaway_Tabs
BOOT_SW1: TS-1088R-02026
C1, C2, C3, C4, C5, C6, C7, C8, C9: 100n; C_0402_1005Metric
C10, C11, C14: 1u; C_0402_1005Metric
C12, C13: 27p; C_0402_1005Metric
C15, C16: 10u; C_0402_1005Metric
D1, D2, D3, D4, D5, D6, D7, D8, D9, D10, D11, D12, D13, D14, D15, D16, D17, D18, D19, D20, D21, D22, D23, D24, D25, D26, D27, D28, D29, D30, D31, D32, D33, D34, D35, D36, D37, D38, D39, D40, D41, D42, D43, D44, D45, D46, D47, D48: SOD-523; D_SOD-523
J1: Conn_01x03; PinHeader_1x03_P2.54mm_Vertical
J2: 78171-0004; Pico-EZmate_PCB_Header
MX1, MX2, MX3, MX4, MX5, MX6, MX7, MX8, MX9, MX10, MX11, MX12, MX13, MX14, MX15, MX16, MX17, MX18, MX19, MX20, MX21, MX22, MX23, MX24, MX25, MX26, MX27, MX28, MX29, MX30, MX31, MX32, MX33, MX34, MX35, MX36, MX37, MX38, MX39, MX40, MX41, MX42, MX43, MX44, MX45, MX46, MX47, MX48: SW_Push; keyswitch_choc12_hotswap_1u
R1, R2: 27; R_0402_1005Metric
R3, R5: 1k; R_0402_1005Metric
R4: 10k; R_0402_1005Metric
RESET_SW1: TS-1088R-02026
U1: RP2040; QFN-56-1EP_7x7mm_P0.4mm_EP3.2x3.2mm
U2: NCP1117-3.3_SOT223; SOT-223-3_TabPin2
U3: W25Q128JVSIQ; SOIC-8_5.23x5.23mm_P1.27mm
Y1: 12MHz 18pF; Crystal_SMD_3225-4Pin_3.2x2.5mm

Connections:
+1V1: C1.1, C2.1, C10.1, U1.23 (DVDD), U1.45 (VREG_VOUT), U1.50 (DVDD)
+3V3: C3.1, C4.1, C5.1, C6.1, C7.1, C8.1, C9.1, C11.1, C14.1, C16.1, R4.2, U1.1 (IOVDD), U1.10 (IOVDD), U1.22 (IOVDD), U1.33 (IOVDD), U1.42 (IOVDD), U1.43 (ADC_AVDD), U1.44 (VREG_IN), U1.48 (USB_VDD), U1.49 (IOVDD), U2.2 (VO), U3.8 (VCC)
+5V: C15.1, J2.1, U2.3 (VI)
/cornelius/D+: J2.3, R1.1
/cornelius/D-: J2.2, R2.2
/cornelius/QSPI_SCLK: U1.52 (QSPI_SCLK), U3.6 (CLK)
/cornelius/QSPI_SD0: U1.53 (QSPI_SD0), U3.5 (DI(IO0))
/cornelius/QSPI_SD1: U1.55 (QSPI_SD1), U3.2 (DO(IO1))
/cornelius/QSPI_SD2: U1.54 (QSPI_SD2), U3.3 (IO2)
/cornelius/QSPI_SD3: U1.51 (QSPI_SD3), U3.7 (IO3)
/cornelius/QSPI_SS: R4.1, R5.2, U1.56 (QSPI_SS), U3.1 (~CS)
/cornelius/SWCLK: J1.1, U1.24 (SWCLK)
/cornelius/SWD: J1.3, U1.25 (SWD)
/cornelius/col0: MX1.1, MX13.1, MX25.1, MX37.1, U1.39 (GPIO27_ADC1)
/cornelius/col1: MX2.1, MX14.1, MX26.1, MX38.1, U1.38 (GPIO26_ADC0)
/cornelius/col2: MX3.1, MX15.1, MX27.1, MX39.1, U1.37 (GPIO25)
/cornelius/col3: MX4.1, MX16.1, MX28.1, MX40.1, U1.36 (GPIO24)
/cornelius/col4: MX5.1, MX17.1, MX29.1, MX41.1, U1.29 (GPIO18)
/cornelius/col5: MX6.1, MX18.1, MX30.1, MX42.1, U1.28 (GPIO17)
/cornelius/col6: MX7.1, MX19.1, MX31.1, MX43.1, U1.14 (GPIO11)
/cornelius/col7: MX8.1, MX20.1, MX32.1, MX44.1, U1.8 (GPIO6)
/cornelius/col8: MX9.1, MX21.1, MX33.1, MX45.1, U1.7 (GPIO5)
/cornelius/col9: MX10.1, MX22.1, MX34.1, MX46.1, U1.6 (GPIO4)
/cornelius/col10: MX11.1, MX23.1, MX35.1, MX47.1, U1.5 (GPIO3)
/cornelius/col11: MX12.1, MX24.1, MX36.1, MX48.1, U1.4 (GPIO2)
/cornelius/row0: D1.1 (K), D2.1 (K), D3.1 (K), D4.1 (K), D5.1 (K), D6.1 (K), D7.1 (K), D8.1 (K), D9.1 (K), D10.1 (K), D11.1 (K), D12.1 (K), U1.3 (GPIO1)
/cornelius/row1: D13.1 (K), D14.1 (K), D15.1 (K), D16.1 (K), D17.1 (K), D18.1 (K), D19.1 (K), D20.1 (K), D21.1 (K), D22.1 (K), D23.1 (K), D24.1 (K), U1.41 (GPIO29_ADC3)
/cornelius/row2: D25.1 (K), D26.1 (K), D27.1 (K), D28.1 (K), D29.1 (K), D30.1 (K), D31.1 (K), D32.1 (K), D33.1 (K), D34.1 (K), D35.1 (K), D36.1 (K), U1.40 (GPIO28_ADC2)
/cornelius/row3: D37.1 (K), D38.1 (K), D39.1 (K), D40.1 (K), D41.1 (K), D42.1 (K), D43.1 (K), D44.1 (K), D45.1 (K), D46.1 (K), D47.1 (K), D48.1 (K), U1.27 (GPIO16)
GND: BOOT_SW1.1, C1.2, C2.2, C3.2, C4.2, C5.2, C6.2, C7.2, C8.2, C9.2, C10.2, C11.2, C12.2, C13.2, C14.2, C15.2, C16.2, J1.2, J2.4, J2.MP (MountPin), RESET_SW1.1, U1.19 (TESTEN), U1.57 (GND), U2.1 (GND), U3.4 (GND), Y1.2, Y1.4
unnamed: BOOT_SW1.2, R5.1
unnamed: C13.1, R3.1, Y1.3
unnamed: D1.2 (A), MX1.2
unnamed: D2.2 (A), MX2.2
unnamed: D3.2 (A), MX3.2
unnamed: D4.2 (A), MX4.2
unnamed: D5.2 (A), MX5.2
unnamed: D6.2 (A), MX6.2
unnamed: D7.2 (A), MX7.2
unnamed: D8.2 (A), MX8.2
unnamed: D9.2 (A), MX9.2
unnamed: D10.2 (A), MX10.2
unnamed: D11.2 (A), MX11.2
unnamed: D12.2 (A), MX12.2
unnamed: D13.2 (A), MX13.2
unnamed: D14.2 (A), MX14.2
unnamed: D15.2 (A), MX15.2
unnamed: D16.2 (A), MX16.2
unnamed: D17.2 (A), MX17.2
unnamed: D18.2 (A), MX18.2
unnamed: D19.2 (A), MX19.2
unnamed: D20.2 (A), MX20.2
unnamed: D21.2 (A), MX21.2
unnamed: D22.2 (A), MX22.2
unnamed: D23.2 (A), MX23.2
unnamed: D24.2 (A), MX24.2
unnamed: D25.2 (A), MX25.2
unnamed: D26.2 (A), MX26.2
unnamed: D27.2 (A), MX27.2
unnamed: D28.2 (A), MX28.2
unnamed: D29.2 (A), MX29.2
unnamed: D30.2 (A), MX30.2
unnamed: D31.2 (A), MX31.2
unnamed: D32.2 (A), MX32.2
unnamed: D33.2 (A), MX33.2
unnamed: D34.2 (A), MX34.2
unnamed: D35.2 (A), MX35.2
unnamed: D36.2 (A), MX36.2
unnamed: D37.2 (A), MX37.2
unnamed: D38.2 (A), MX38.2
unnamed: D39.2 (A), MX39.2
unnamed: D40.2 (A), MX40.2
unnamed: D41.2 (A), MX41.2
unnamed: D42.2 (A), MX42.2
unnamed: D43.2 (A), MX43.2
unnamed: D44.2 (A), MX44.2
unnamed: D45.2 (A), MX45.2
unnamed: D46.2 (A), MX46.2
unnamed: D47.2 (A), MX47.2
unnamed: D48.2 (A), MX48.2
unnamed: RESET_SW1.2, U1.26 (RUN)
unnamed: R2.1, U1.46 (USB_DM)
unnamed: R1.2, U1.47 (USB_DP)
unnamed: C12.1, U1.20 (XIN), Y1.1
unnamed: R3.2, U1.21 (XOUT)

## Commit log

2021-07-13 Fix typo (form → foam)
2021-07-17 Add plate and foam data
    [middle-foam.dxf, switch-foam.dxf, switch-plate.dxf]
2021-08-08 Add mock-up-body
    [mock-up-body.step]
2023-11-12 Add pcb files
    [cornelius.kicad_pcb, cornelius.kicad_sch]
2023-11-12 Squashed 'pcb/kbd/' content from commit 51de1d9
    git-subtree-dir: pcb/kbd
    git-subtree-split: 51de1d90c9d909ca0fc34986691014b41b4bf398
2023-11-12 Squashed 'pcb/kbd/' changes from 51de1d9..d3325a6
    d3325a6 Update
    e87945a Update footprints for crkbd4
    git-subtree-split: d3325a6fa2d7ededd6e092e9450e59ab983efbb4
    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
2023-11-12 Add hotswap pcb
    [BOM-cornelius.csv, cornelius.kicad_pcb, cornelius.kicad_sch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]
2023-11-12 Squashed 'pcb/kbd/' content from commit d3325a6
    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
2023-11-12 Update jlcpcb files
    [cornelius.kicad_pcb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]
2023-11-12 Squashed 'pcb/kbd/' changes from d3325a6..e24354d
    e24354d Fix choc footprints
    git-subtree-split: e24354ddaec81db4c7b912fca939025e305833db
    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
2023-11-12 Add solder pcb
    [BOM-cornelius.csv, cornelius.kicad_pcb, cornelius.kicad_sch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]
2023-11-12 Squashed 'pcb/common/kbd/' content from commit 79230bb
    git-subtree-dir: pcb/common/kbd
    git-subtree-split: 79230bbdc12f02f9bfed5b3f6131fb8971f0ae00
2023-11-12 Update solder pcb
    [BOM-cornelius.csv, cornelius.kicad_pcb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]
2023-11-15 Update zd
    [cornelius.kicad_sch]
2023-11-15 Fix pass capacitor
    [BOM-cornelius.csv, cornelius.kicad_pcb, cornelius.kicad_sch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]
2023-11-15 Cleanup directories
    [BOM-cornelius.csv, cornelius.kicad_pcb, cornelius.kicad_sch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]
2023-11-15 Change plate data from dxf to svg
    [middle-foam.dxf, switch-foam.dxf, switch-plate.dxf]
2024-08-31 Separate to v1 directories
    [BOM-cornelius.csv, cornelius.kicad_pcb, cornelius.kicad_sch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]
2024-08-31 Fix paths
    [cornelius.kicad_sch]
2024-08-31 Add v2 files
    [BOM-cornelius-chocolate.csv, cornelius-chocolate.kicad_pcb, cornelius-chocolate.kicad_sch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]
2024-08-31 Genarate jlcfiles
    [BOM-cornelius.csv, cornelius.kicad_pcb, cornelius.kicad_sch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]
2024-08-31 Squashed 'pcbs/v1/common/kbd/' content from commit c53bf51
    git-subtree-dir: pcbs/v1/common/kbd
    git-subtree-split: c53bf519ed9e0a498869ab56d44385f89ec54b36
2024-08-31 Squashed 'pcbs/v2/common/kbd/' content from commit c53bf51
    git-subtree-dir: pcbs/v2/common/kbd
    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
2024-12-13 Update foams for v2
    [middle-foam.dxf, switch-ixpe-foam.dxf]
